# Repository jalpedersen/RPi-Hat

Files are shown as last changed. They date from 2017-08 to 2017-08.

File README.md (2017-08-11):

% RPi B+ Hat

Raspberry Pi B+ Hat
============================

Expansion Board
----------------------------

This is a project template for a 
[Raspberry Pi B+ Hat](https://github.com/raspberrypi/hats).

This is based on work of [xesscorp](https://github.com/xesscorp/RPi_Hat_Template)

This version includes a CAT24C32 EEPROM for ID EEPROM as well as DS1340 RTC for
keeping track of time.

All headers (except ID_SC and ID_SD) are brought out into a separate header for
easy access. Also two small prototyping areas are provided

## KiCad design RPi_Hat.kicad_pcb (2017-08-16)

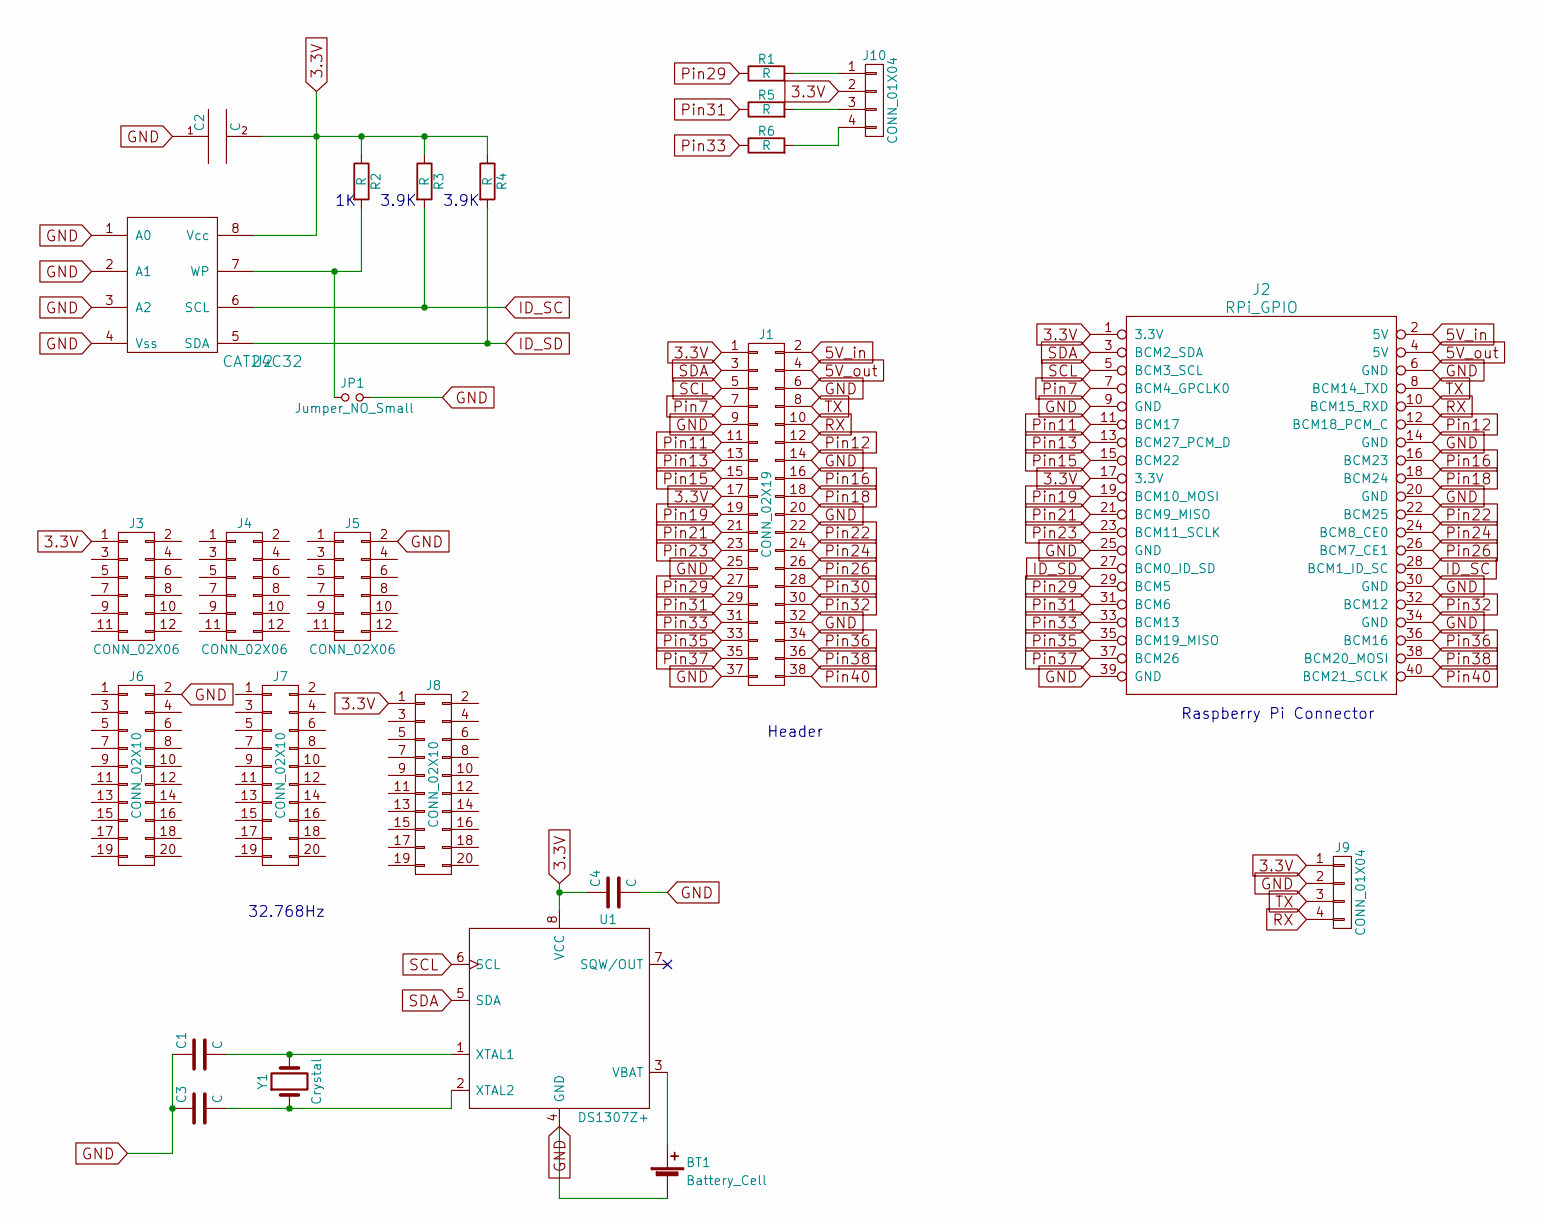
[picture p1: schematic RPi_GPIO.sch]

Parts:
BT1: Battery_Cell; Keystone_1058_1x2032-CoinCell
C1, C2, C3, C4: C; C_0805_HandSoldering
J1: CONN_02X19; Pin_Header_Straight_2x19_Pitch2.54mm
J2: RPi_GPIO; Pin_Header_Straight_2x20_Pitch2.54mm
J3, J4, J5: CONN_02X06; Pin_Header_Straight_2x06_Pitch2.54mm
J6, J7, J8: CONN_02X10; Pin_Header_Straight_2x10_Pitch2.54mm
J9: CONN_01X04; Pin_Header_Straight_1x04_Pitch2.54mm
J10: CONN_01X04; Pin_Header_Straight_1x04_Pitch1.27mm
JP1: Jumper_NO_Small; Pin_Header_Straight_2x01_Pitch2.54mm
R1, R2, R3, R4, R5, R6: R; R_0805_HandSoldering
U1: DS1307Z+; SOIC-8-N
U2: CAT24C32; SOIC-8-N
Y1: Crystal; Crystal_SMD_EuroQuartz_EQ161-2pin_3.2x1.5mm_HandSoldering

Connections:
3.3V: C2.2, C4.1, J1.1, J1.17, J2.1 (3.3V), J2.17 (3.3V), J3.1, J8.1, J9.1, J10.2, R2.1, R3.1, R4.1, U1.8 (VCC), U2.8 (Vcc)
5V_in: J1.2, J2.2 (5V)
5V_out: J1.4, J2.4 (5V)
GND: BT1.2 (-), C1.1, C2.1, C3.1, C4.2, J1.6, J1.9, J1.14, J1.20, J1.25, J1.32, J1.37, J2.6 (GND), J2.9 (GND), J2.14 (GND), J2.20 (GND), J2.25 (GND), J2.30 (GND), J2.34 (GND), J2.39 (GND), J5.2, J6.2, J9.2, JP1.2, U1.4 (GND), U2.1 (A0), U2.2 (A1), U2.3 (A2), U2.4 (Vss)
ID_SC: J2.28 (BCM1_ID_SC), R3.2, U2.6 (SCL)
ID_SD: J2.27 (BCM0_ID_SD), R4.2, U2.5 (SDA)
unnamed: BT1.1 (+), U1.3 (VBAT)
unnamed: C1.2, U1.1 (XTAL1), Y1.2
unnamed: C3.2, U1.2 (XTAL2), Y1.1
unnamed: J10.1, R1.2
unnamed: J10.3, R5.2
unnamed: J10.4, R6.2
unnamed: JP1.1, R2.2, U2.7 (WP)
Pin7: J1.7, J2.7 (BCM4_GPCLK0)
Pin11: J1.11, J2.11 (BCM17)
Pin12: J1.12, J2.12 (BCM18_PCM_C)
Pin13: J1.13, J2.13 (BCM27_PCM_D)
Pin15: J1.15, J2.15 (BCM22)
Pin16: J1.16, J2.16 (BCM23)
Pin18: J1.18, J2.18 (BCM24)
Pin19: J1.19, J2.19 (BCM10_MOSI)
Pin21: J1.21, J2.21 (BCM9_MISO)
Pin22: J1.22, J2.22 (BCM25)
Pin23: J1.23, J2.23 (BCM11_SCLK)
Pin24: J1.24, J2.24 (BCM8_CE0)
Pin26: J1.26, J2.26 (BCM7_CE1)
Pin29: J1.27, J2.29 (BCM5), R1.1
Pin30: J1.28
Pin31: J1.29, J2.31 (BCM6), R5.1
Pin32: J1.30, J2.32 (BCM12)
Pin33: J1.31, J2.33 (BCM13), R6.1
Pin35: J1.33, J2.35 (BCM19_MISO)
Pin36: J1.34, J2.36 (BCM16)
Pin37: J1.35, J2.37 (BCM26)
Pin38: J1.36, J2.38 (BCM20_MOSI)
Pin40: J1.38, J2.40 (BCM21_SCLK)
RX: J1.10, J2.10 (BCM15_RXD), J9.4
SCL: J1.5, J2.5 (BCM3_SCL), U1.6 (SCL)
SDA: J1.3, J2.3 (BCM2_SDA), U1.5 (SDA)
TX: J1.8, J2.8 (BCM14_TXD), J9.3

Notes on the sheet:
Header
Raspberry Pi Connector
32.768Hz
3.9K

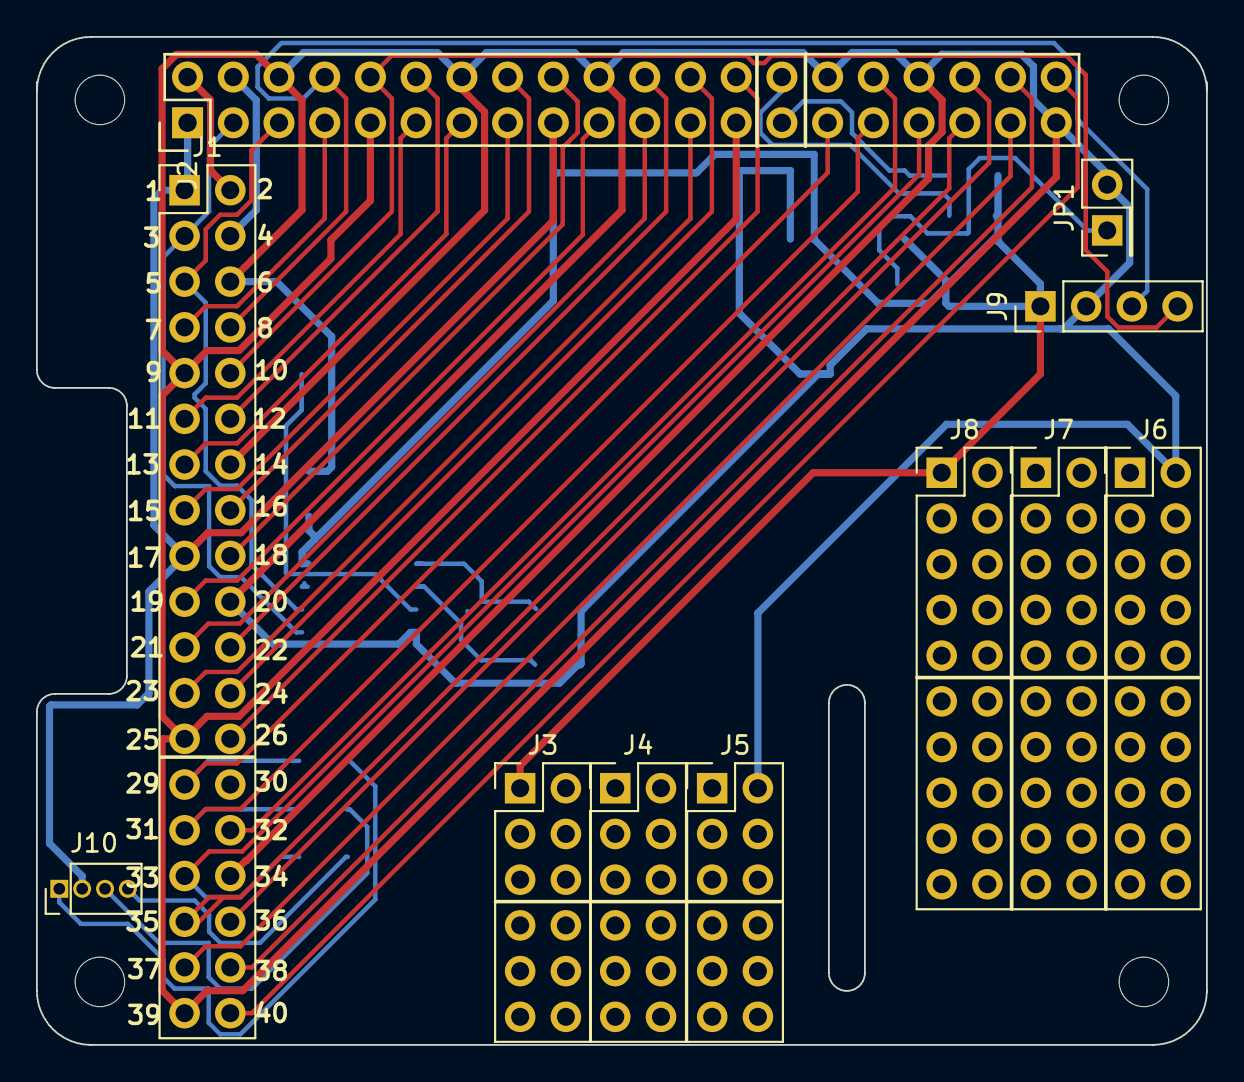
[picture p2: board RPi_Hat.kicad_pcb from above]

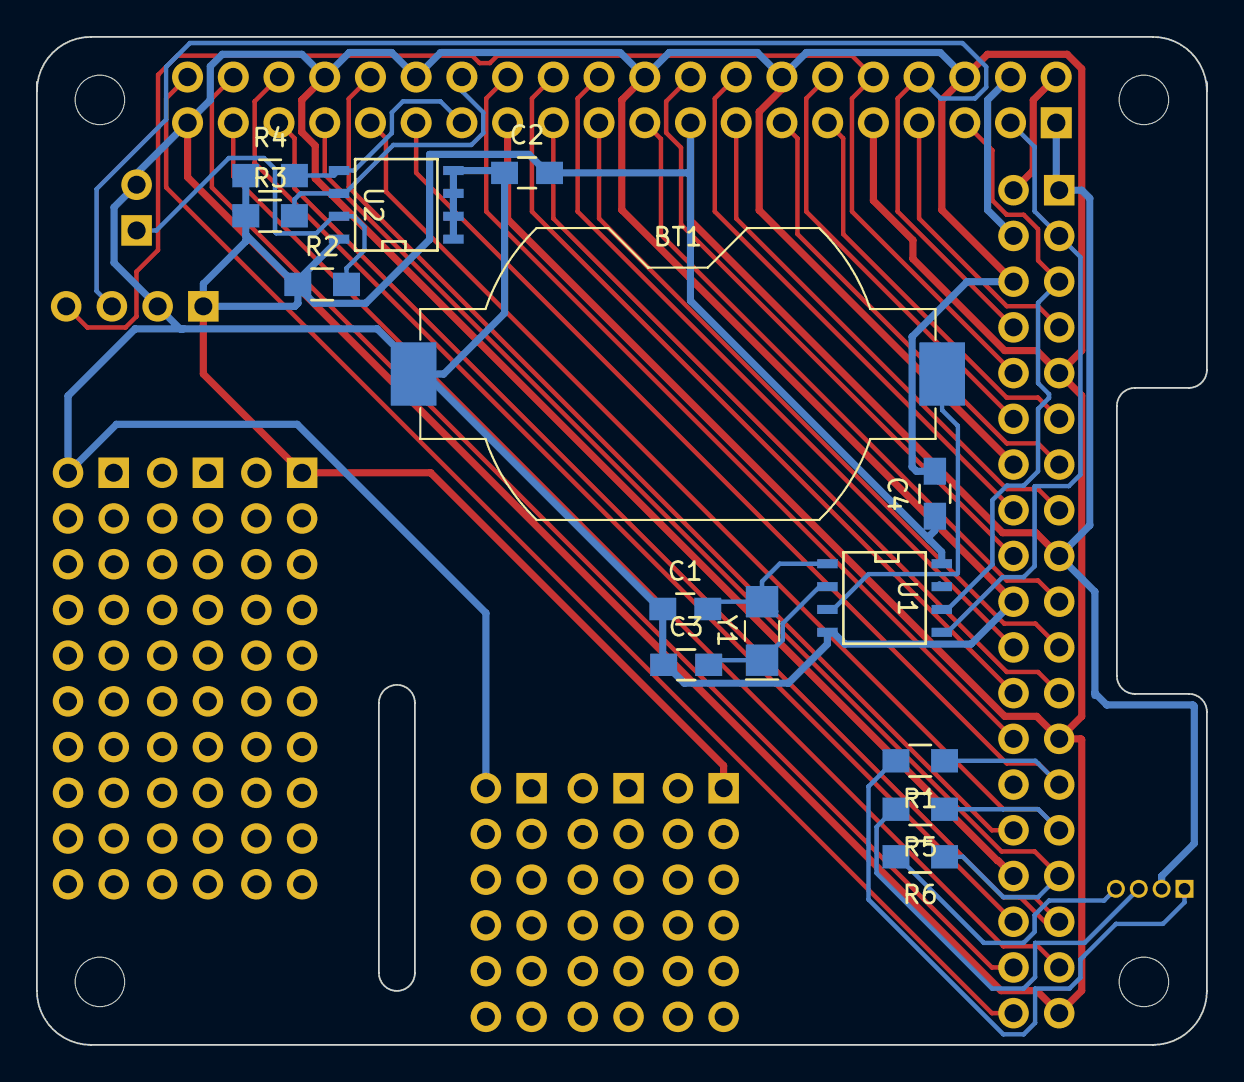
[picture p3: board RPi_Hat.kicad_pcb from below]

Board: 2 copper layers, 65.0 x 56.0 mm, 25 parts (14 on the bottom side), 39 nets.

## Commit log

2017-08-14 cleanup and add RX/TX header
    [RPi_GPIO.sch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]
2017-08-15 support MCP7940N as well as ds1338/ds1340
    [RPi_GPIO.sch, RPi_Hat.kicad_pcb]
2017-08-15 add room for an rgb led
    [RPi_GPIO.sch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]
2017-08-15 use connector footprint for LED as the standard one violated the DRC
    [RPi_GPIO.sch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]
2017-08-16 move LED to front and make sure there is enough clearance between components
    [RPi_Hat-B.Cu.gbl, RPi_Hat-B.Mask.gbs, RPi_Hat-B.SilkS.gbo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]
2017-08-16 support SMD RGB LED as well
    [RPi_GPIO.sch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]
2017-08-16 remove SMD LED
    [RPi_GPIO.sch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]
2017-08-16 commit updated gerber.zip
